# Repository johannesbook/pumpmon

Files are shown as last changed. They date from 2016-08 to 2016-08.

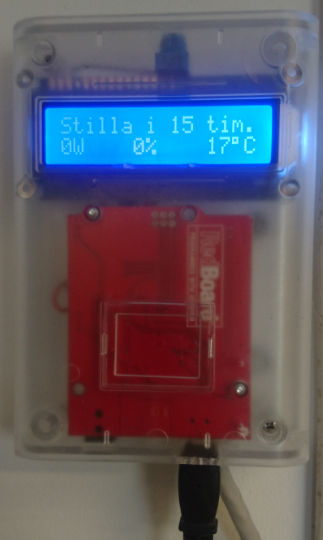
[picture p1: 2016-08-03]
pic.png

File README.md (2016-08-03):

# pumpmon
tool to monitor garden water pump

I have an automatic garden water pump that isn't reliable. Sometimes the pressostat fails, leaving the pump running without anything using water. This causes the water to boil finally, breaking the hose sealings, very annoying. 

So, since fixing the pump is boring and electronics is fun, I made a pump monitor. Quick overview: 

- monitoring temperature, shutting the pump down if too hot, and warning with a sound signal if too low (freeze risk)
- monitoring power going into the pump, shutting down if too high (broken bearings?)
- monitoring if there is water on the floow
- displaying status on a display (pump used power, temperature, time since last run and run-ratio for the last 3 hours in % (the last two helps to find leaks etc.)

Parts used: 
- regular arduino uno
- standard 16 x 2 display (https://www.adafruit.com/products/1447)
- temp sensor (https://www.adafruit.com/products/381)
- a Rogowski coil to measure power (i.e. current) going into the pump (https://www.digikey.com/product-detail/en/talema-group-llc/AC1020/1295-1095-ND/3881394)
- standard passive buzzer (https://www.kjell.com/se/sortiment/el-verktyg/elektronik/arduino/moduler/passiv-summer-for-arduino-p87887)
- water alarm (https://www.conrad.se/Vattendetektor-Schabus-Aquastopp-SHT-216-300260-N%e4tanslutning.htm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)

I already had the water alarm, if not I probably would have used a relay controller and made a simple water detector myself. 

Non-standard solutions that might need explanation:

Water alarm:
I tapped into the water alarm on the sensor cable. It shows 12V in idle, and 3V when the alram has gone off, which makes it possible for the Arduino to detect status (A5). Also, using a standard NPN to short these wires to shut down the pump (D2).

Current sensor:
Using the coil gives an AC voltage output, proportional to the current flowing through it (100 mV / A). To avoid damaging the arduino I used a schottky diode to cut off the negative part, and a small capacitor to add some smoothness. 

The rest should be self-explanatory. If not just ask.

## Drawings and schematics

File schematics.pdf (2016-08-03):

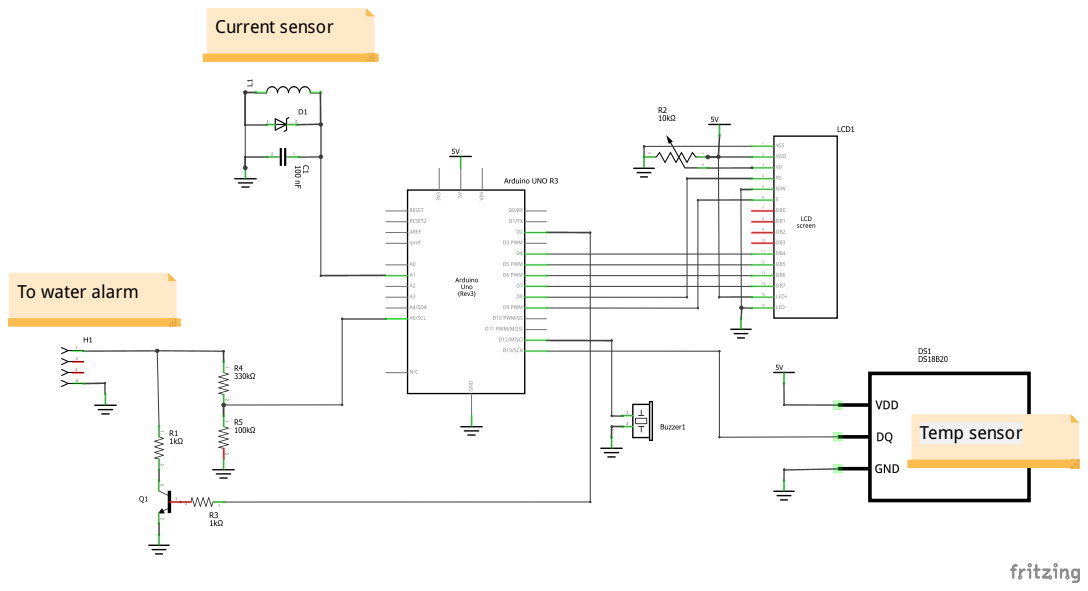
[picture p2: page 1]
Current sensor; Temp sensor

To water alarm

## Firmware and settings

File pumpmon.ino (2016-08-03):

/* A small tool to monitor my garden water pump. Features:
 * - checking pump temperature (high and low). Low = risk for freeze, high = running dry.
 * - checking for too high power use (running heavy / mechanical failure). Ignoring high power during first 10 seconds (to ignore intermittent events)
 * - can turn off pump if error occurs (high temp / high power)
 * - reads water alarm status and sounds alarm if floor is wet
 * - displays how much it was running the last X hours
 * - displays time since last run
 */

#include <OneWire.h>
#include <DallasTemperature.h>
#include <LiquidCrystal.h>

const int maxPower = 900; //kill pump if power goes above (pump is rated 900W)
const int maxTemp = 40; //kill pump if pump house goes above
const int minTemp = 5; //warn if temp goes below this figure

/* Pin definitions */
LiquidCrystal lcd(8, 9, 4, 5, 6, 7); //LCD digital pins
#define ONE_WIRE_BUS 13 //Temp sensor (DS onewire)
#define buzzerPin 12 //passive piezo buzzer
#define butPin A0 //buttons on LCD module (R ladder)
#define curSense A1 //current sensor
#define waterPin A5 //water sensor pin (12V @ normal, ~3V when triggered)
#define shutdownPin 2 //pin to trigger shutdown (using the water alarm)

OneWire oneWire(ONE_WIRE_BUS);
DallasTemperature sensors(&oneWire);

bool freezeFlag = false;
int overpowerCount = 0;

const int historyLength = 4*60; //4 hours * 60 minutes
float runHistory[historyLength];
int runBucket = 0;
int idleBucket= 0;
int loopCount = 0;
unsigned long timesinceLast; //time since last run, in seconds

void setup() {
  bootSound();
  sensors.begin();
  Serial.begin(115200);
  lcd.begin(16, 2);   // set up the LCD's number of columns and rows
  printStatus("Allt verkar okej");
  Serial.print("Startar...");
  for (int i=0; i<historyLength; i++) {
    runHistory[i] = 0;
  }
}


void loop() {  
  int temp; //pump house temperature in deg C
  float power; //power used by the pump in W
  float runTime; //ratio in %
  bool waterStatus; //if water alarm is triggered

  //TEMPERATURE
  if (loopCount == 0) { //unneccessary to do this all the time, temp measurements takes a long time
    //Temperature at the pump house (probably close to water temperature after running some time)  
    temp = readTemp();
    printTemp(temp); //print temp to display
    checkTemp(temp); //check temp for high and low, and take action
    loopCount = 0;
  }
  loopCount++;
    
  //POWER
  power = readPower();
  printPower(power); //print currently used power to display
  checkPower(power); //check if power is too high (something broke)

  //TIME SINCE LAST RUN
  calculatetimesinceLast(power);
  printtimesinceLast();
  
  //RUNNING TIME RATIO
  runTime = calculaterunTime(power);
  printrunTime(runTime);

  //WATER ALARM
  waterStatus = readWateralarm();
  printwaterStatus(waterStatus);

  //TEST BUTTON
  if ((analogRead(A0) > 730) and (analogRead(A0) < 750) ) { //if select button pressed
    shutDown();
  }
}

void printStatus(String msg) {
  lcd.setCursor(0, 0);
  lcd.print(msg);
}

void shutDown() {
  digitalWrite(shutdownPin, HIGH);
}

unsigned long lastmillis = 0;

void printtimesinceLast() {
  if (timesinceLast < 1) {
    printStatus("Pumpar.         ");
  }
  if ( (timesinceLast >= 2) and (timesinceLast < 60) ) {
    printStatus("Stilla.         ");
  }  
  if ( (timesinceLast >= 60) and (timesinceLast < 3600) ) {
    printStatus("Stilla i " + String(int(timesinceLast/60)) + " min.    ");
  }
  if (timesinceLast >= 3600) {
    printStatus("Stilla i " + String(int(timesinceLast/3600)) + " tim.    ");
  }
  Serial.print(lastmillis);
  Serial.print("  |  ");
  Serial.println(timesinceLast);
}

void calculatetimesinceLast(int pwr) {
  if (pwr > 50) {
    timesinceLast = 0; //pump running, reset timer
    lastmillis = millis();
  } else {
    timesinceLast = (millis() - lastmillis) / 1000;
  }
}

void printrunTime(float runTime) {
  lcd.setCursor(6, 1);
  lcd.print(int(runTime));
  lcd.print("%");  
}

float calculaterunTime(int pwr) {
  int second = ((millis()/1000) % 60) + 1;
  int i;
  float ratio;

  if (second < 60) { //average during the minute
    if (pwr > 50) { //pump is running now
      runBucket++;
    } else {
      idleBucket++;
    }
  } else { //one minute has passed, store the number from this minute
    for (i = historyLength-1; i > 0; i--) {
      runHistory[i] = runHistory[i-1]; //thrash the oldest sample and rotate the buffer one step
    }
    runHistory[0] = (float)runBucket / ((float)runBucket + (float)idleBucket); 
    idleBucket = 0;
    runBucket = 0;
    delay(1000); //to make sure we won't store more times this same second
  }

  //calculate average on-ratio
  for (i = 0; i<historyLength; i++) {
    ratio += runHistory[i];
  }

  ratio = 100 * ratio / historyLength; // *100 since it's %
  return round(ratio);
}

bool readWateralarm() {
  int val = analogRead(waterPin);
  if (val < 300) {
    return true;
  } else {
    return false;
  }
}

void printwaterStatus(bool status) {
  if (status) {
    printStatus("Wet on floor!   ");
  }
}

int readPower() {
  float pwr = 0;

  for (int i = 0; i < 2000; i++) {  //average over ~200 ms = 10 periods @ 50 Hz
    pwr += analogRead(curSense); //one read takes ~100 us
  }
  pwr = pwr / 2000.0; //we had 2000 samples
  pwr = pwr * 2.0; //since only half the period is visible (single-wave rectifying)
  pwr = pwr / 20.48; //divide by 20.48 since 1A <=> 100 mV <=> ADC value of 20,48 (1024 = 5V)
  pwr = pwr * 230.0; //multiply by mains voltage to get power

  return round(pwr);
}

void printPower(int pwr) {
  lcd.setCursor(0,1);
  lcd.print(pwr);
  lcd.print("W  "); //a few extra spaces to delete previous writes on display
}

void checkPower(int pwr) {
  if (pwr > maxPower) {
    overpowerCount++;
    delay(1000); //to ignore pump startup power fail
  }
  if (pwr < 50) { //reset if pump is stopped, if not, alarm would sound after ten starts
    overpowerCount = 0;
  }
  if (overpowerCount > 10) {
    shutDown();
    printStatus("Effektlarm!     ");
    while(1) {
      alarmSound();
    }    
  }
  
}

void checkTemp(int tmp) { //if temp below +3, sound alarm and do nothing else
  //check for freezing:
  if (tmp <= minTemp) {
    freezeFlag = true; //needs reset to clear flag
  }
  if (freezeFlag) {
    printStatus("Frysrisk!       ");
    for (int i = 0; i < 100; i++) {  //sound the alarm, but also update temperature on display once and a while
      alarmSound();
    }
  }

  //check if running dry:
  if (tmp >= maxTemp) {
    printStatus("Varmt!");
    shutDown();
    while(1);
  }

  
}

void printTemp(int tmp) {
  lcd.setCursor(12, 1);
  lcd.print(tmp);
  lcd.print(char(223));
  lcd.print("C");  
}

int readTemp() {
  sensors.requestTemperatures();
  return round(sensors.getTempCByIndex(0));
}


/*
char readButtons() {
  int val = analogRead(butPin);
  int margin = 50;
  int select = 7413;
  int left = 5043;
  int up = 1443;
  int down = 3293;
  int right = 23;
  
  if (val < 7430
}
*/


void alarmSound() {
  for (int i = 2000; i<4000; i++) {
    tone(buzzerPin,i);
  }
  for (int i = 4000; i>2000; i--) {
    tone(buzzerPin,i);
  }
}


void bootSound() {
  int speed = 100;  
  
  tone(buzzerPin,1760,speed); //A
  delay(speed);
  tone(buzzerPin,2637,speed); //E
  delay(speed);
  tone(buzzerPin,3520,speed); //A
  delay(speed);  
}

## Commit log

2016-08-03 added schematics
    [schematics.fzz]
2016-08-25 bug fix + cleanups
    - Fixed bug with temp only read on startup
    - Added correction factor to make power reading accurate
    - Made power read averaging time longer to make display update less
    flickering
    - Cleaned up / removed some serial debug prints
